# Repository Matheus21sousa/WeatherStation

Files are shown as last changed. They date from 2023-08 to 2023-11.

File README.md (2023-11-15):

# PROJETO -> Estação meteorológica de baixo custo!

> **Strater:** *Matheus M. Sousa*
>
> **Contributors:** *Marcos Paulo L. Resende*; *André Luiz V. Silva*; *Juvenal Caetano de Barcelos*; *Júlio César Neves dos Santos*
>
> O presente repositório, visa documentar a trajetória por trás da elaboração de uma estação meteorológica com base em Arduíno e peças impressas.
>
> A utilização de todo e qualquer arquivo aqui presente deve seguir a metodologia de citação com base nas normas estabelecidas pela ABNT. 

---

**COMPONENTES ELETRÔNICOS:**

Como microcontrolador, pode ser utilizado qualquer dispositivo ***Arduino*** ou ***ESP***.

Abaixo, estão listados todos os componentes eletrônicos adicionais:

| *NOME* | *QUANTIDADE* | *FUNÇÃO* |
| :--- | :---: | :--- |
| **DHTxx** | 01 | Umidade e temperatura do ar |
| **SHT20** | 01 | Umidade e temperatura do solo |
| **Hall 49e** | 02 | Determina o número de basculadas |
| **RTC - DS3231** | 01 | Armazena informações de data e hora |
| **Módulo micro SD - 4MD36** | 01 | Grava informações em cartão micro SD |

---

**INSTRUÇÕES PARA IMPRESSÃO DAS PEÇAS:**

- **Abrigo meteorológico:**
  1. *Peça A:* Base;
  2. *Peça B:* Peças intermediárias (mínimo 4);
  3. *Peça C:* Topo;
  4. *Espaçador:* Peças de 1 cm de altura para limitar a distância de encaixe entre as peças anteriores;
- **Báscula:**
  - Imprimir a peça com altura entre camadas igual ou inferior á 0,2 mm;
  - Reduzir a rugosidade dos compartimentos com o uso de uma lixa d'água;
  - A volumetria dos compartimentos deve ser estimada por meio de testes laboratoriais;  
- **Funil:**
  - Fundir as peças (*Funil externo* + *Funil interno* + *Funil interno - suporte*) c/ cola *super bonder*;
  - Verificar se orifício do funil interno não esteja obstruído após impressão; 

---

**EVENTOS PRESENTES:**

| *ACRÔNIMO* | *EVENTO* | *EDIÇÃO* | *LOCAL* |
| :---: | :---: | :---: | :---: |
| **MNR** | Mostra nacional de robótica | 2023 | Salvador |
| **SIN** | XIII Simpósio de iniciação científica | 2023 | Patos de Minas |
| **SIN** | XII Simpósio de iniciação científica | 2022 | Uberlândia |

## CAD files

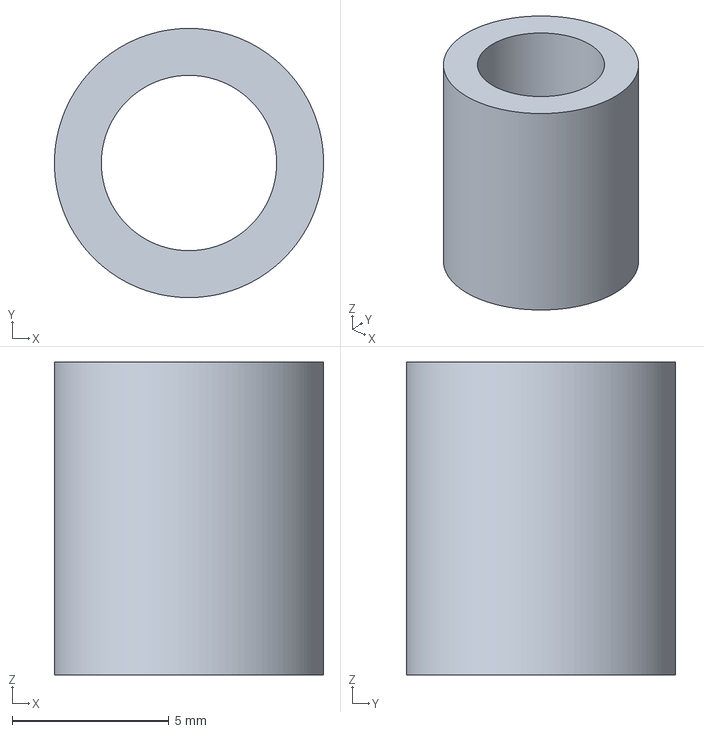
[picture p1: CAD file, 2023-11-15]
3D_Parts/WS - Abrigo met. - Espaçador .3mf
8.60 x 8.60 x 10.0 mm

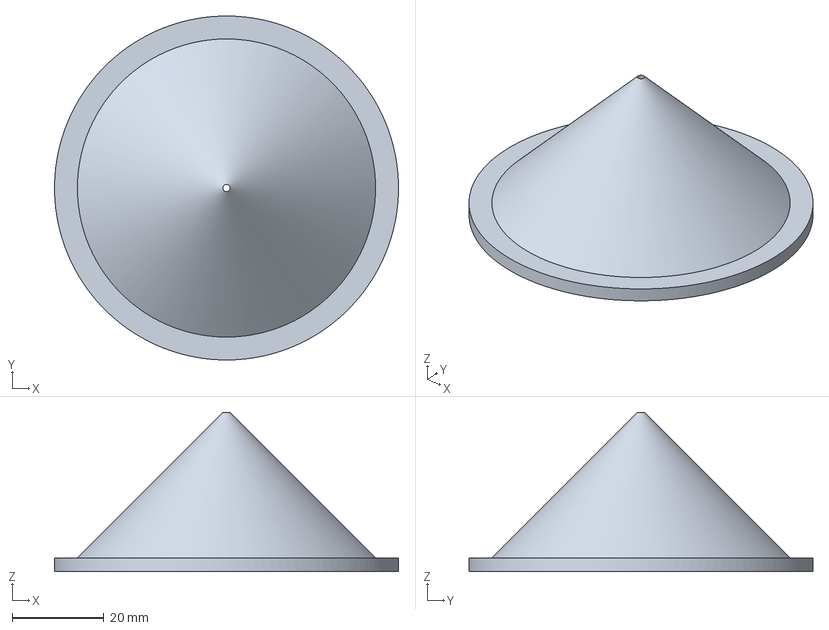
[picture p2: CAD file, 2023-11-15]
3D_Parts/WS - Pluviômetro - Funil interno .3mf
75.0 x 75.0 x 34.7 mm

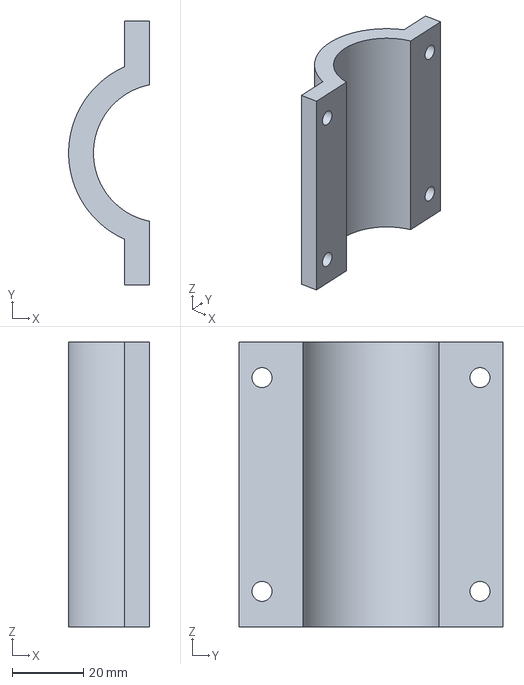
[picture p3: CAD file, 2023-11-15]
3D_Parts/WS - Trava universal suportes .3mf
22.7 x 74.0 x 80.0 mm

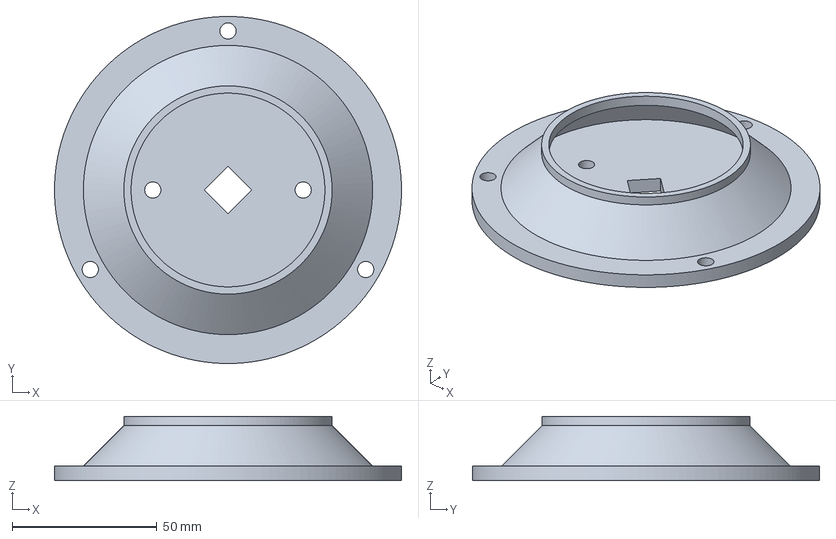
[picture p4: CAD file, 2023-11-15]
3D_Parts/WS - Abrigo met. - Peça A .3mf
120.0 x 120.0 x 22.1 mm

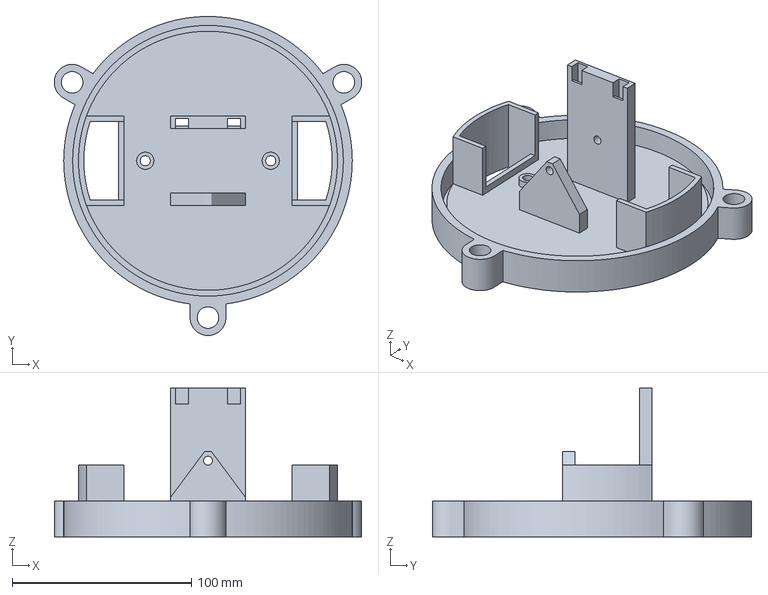
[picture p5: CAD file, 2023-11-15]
3D_Parts/WS - Pluviômetro - Extra I .3mf
171.6 x 178.0 x 83.0 mm

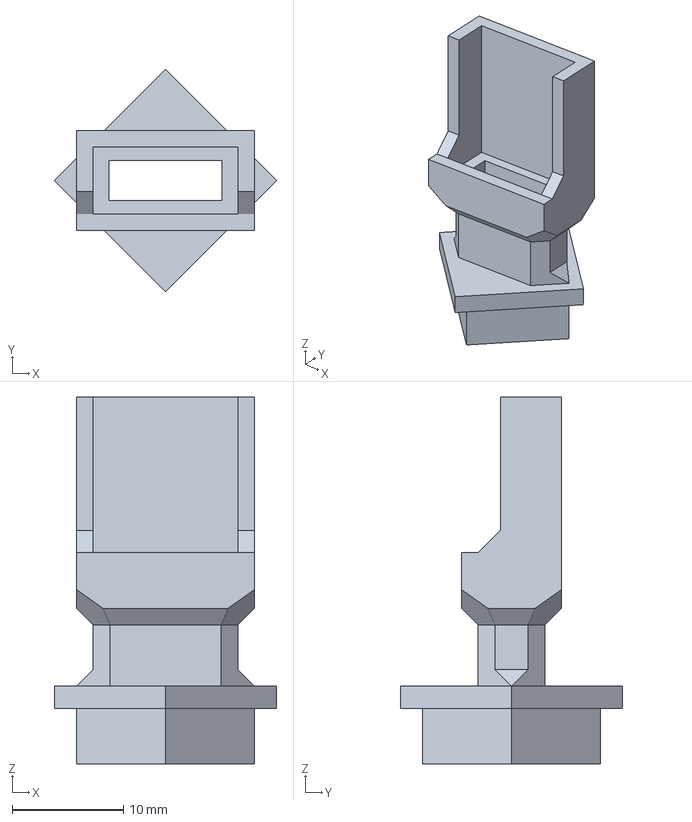
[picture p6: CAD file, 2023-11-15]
3D_Parts/WS - Abrigo met. - Suporte DHT .3mf
20.0 x 20.0 x 33.0 mm

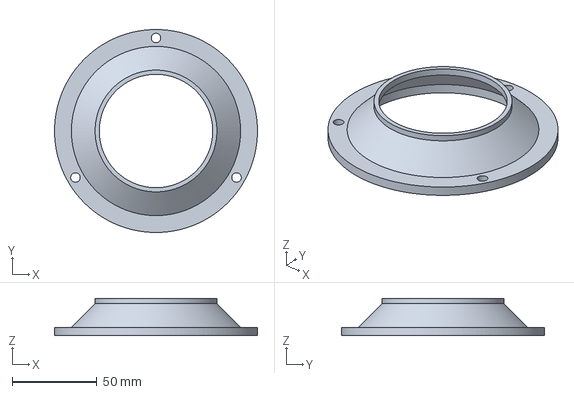
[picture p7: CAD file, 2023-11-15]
3D_Parts/WS - Abrigo met. - Peça B .3mf
120.0 x 120.0 x 22.1 mm

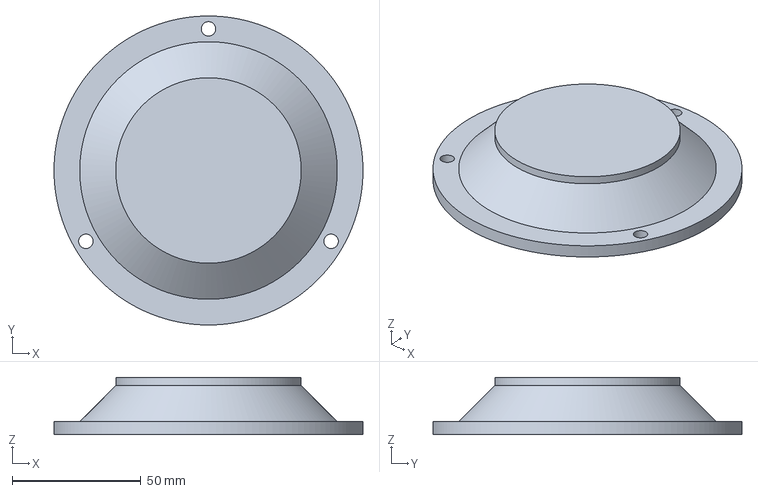
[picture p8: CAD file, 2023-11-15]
3D_Parts/WS - Abrigo met. - Peça C .3mf
120.0 x 120.0 x 22.1 mm

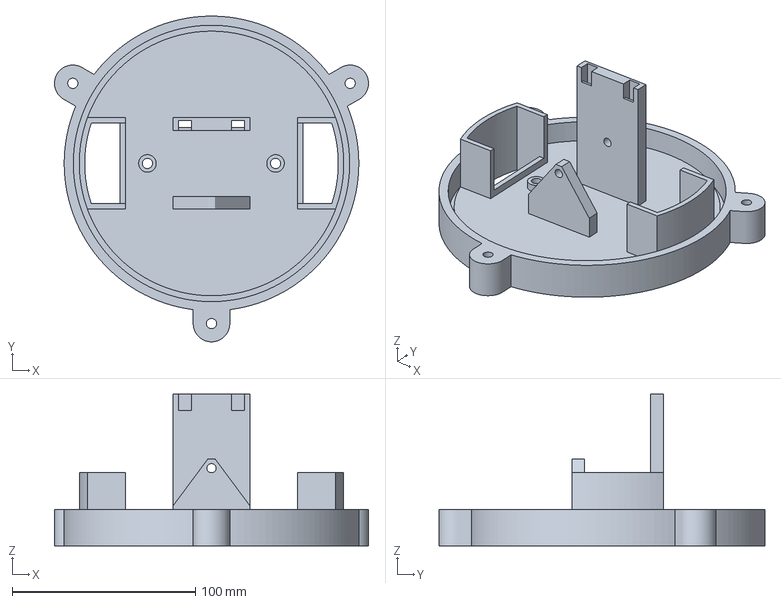
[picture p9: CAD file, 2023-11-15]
3D_Parts/WS - Pluviômetro - Base .3mf
171.6 x 178.0 x 83.0 mm

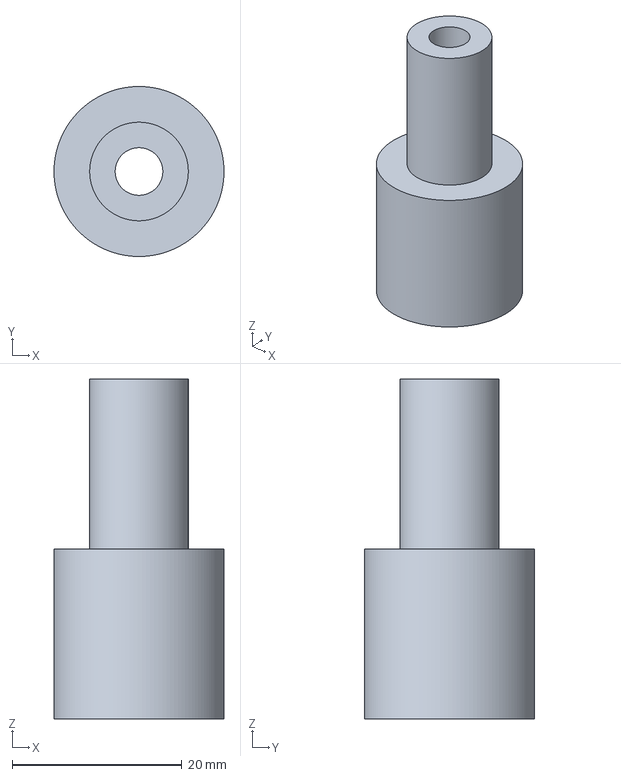
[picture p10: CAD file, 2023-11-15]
3D_Parts/WS - Pluviômetro - Extra II .3mf
20.0 x 20.0 x 40.0 mm

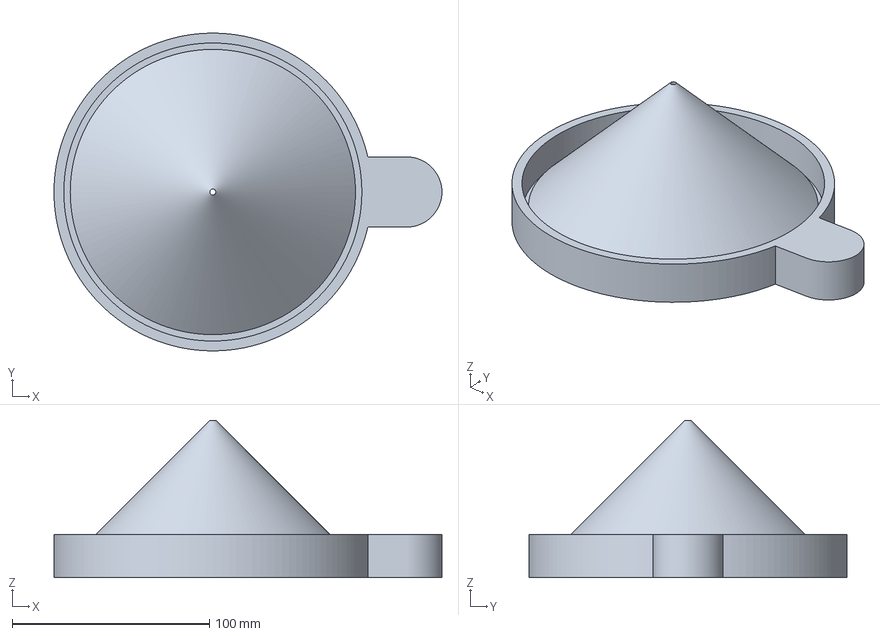
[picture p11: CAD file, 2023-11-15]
3D_Parts/WS - Pluviômetro - Funil externo .3mf
196.6 x 161.0 x 79.8 mm

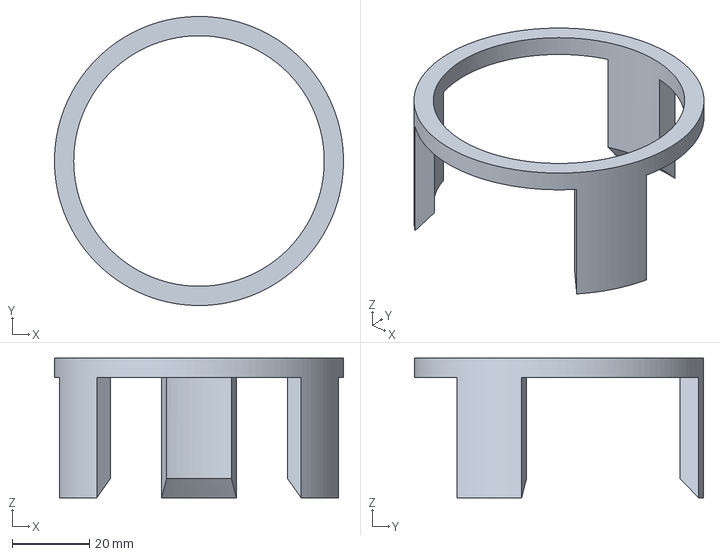
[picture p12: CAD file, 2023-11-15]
3D_Parts/WS - Pluviômetro - Junção funil .3mf
75.0 x 75.0 x 36.2 mm

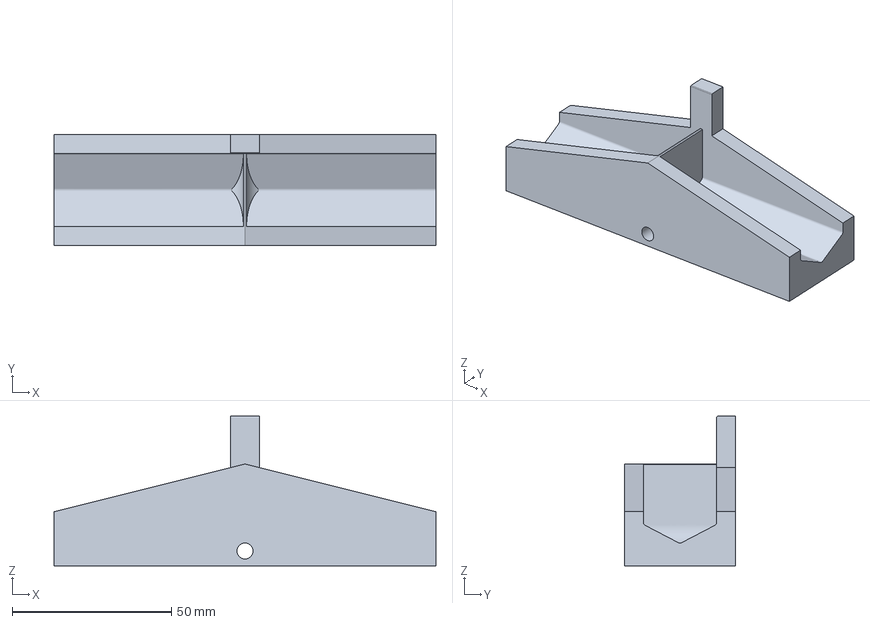
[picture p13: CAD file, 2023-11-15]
3D_Parts/WS - Pluviômetro - Báscula .3mf
120.0 x 35.0 x 47.0 mm

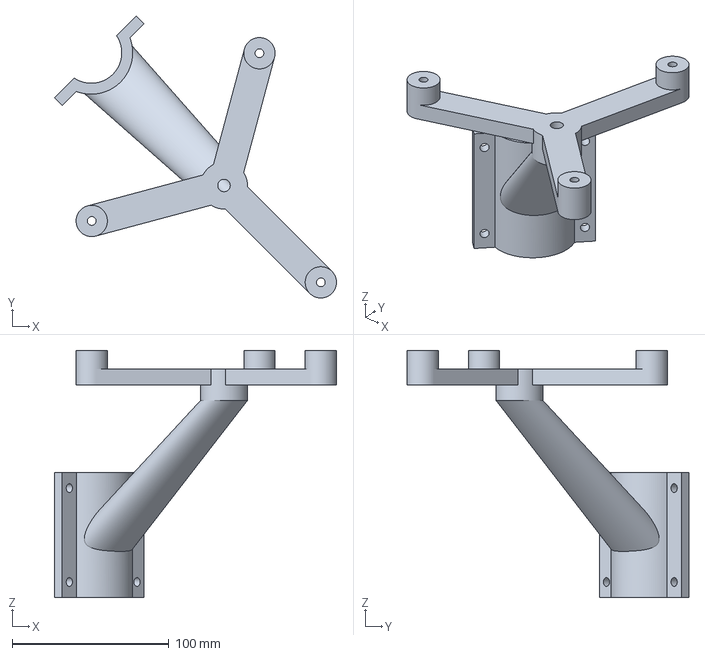
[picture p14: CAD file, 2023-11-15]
3D_Parts/WS - Suporte pluviômetro .3mf
180.2 x 180.2 x 158.0 mm

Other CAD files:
3D_Parts/WS - Suporte abrigo met. .3mf

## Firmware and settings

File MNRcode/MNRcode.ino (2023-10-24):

// MADE BY: Matheus Martins de Sousa //
//
// O presente projeto é aberto a correções
// Use com sabedoria!
// :)
//

// DESCRIÇÃO: Uso de sensores hall para determinar a pluviometria; 

// BIBLIOTECAS UTILIZADAS
#include <Adafruit_Sensor.h>
#include <DHT.h>
#include <DHT_U.h>

// DEFINIÇÃO DE PORTAS
#define DHTPIN 7
#define hallPinD A5 
#define hallPinE A4
// Portas hall (model 49e):
// 5V - Esquerda
// GND - Central
// DATA - Direita

// Selecione a seguir o sensor que está sendo utilizado, retirando as // no início da linha:
#define DHTTYPE    DHT11     // DHT 11
//#define DHTTYPE    DHT22     // DHT 22 (AM2302)
//#define DHTTYPE    DHT21     // DHT 21 (AM2301)

// CONFIGURAÇÃO SENSOR DHT - "TYPE"
DHT_Unified dht(DHTPIN, DHTTYPE);

// VARIÁVEL DE TEMPO
uint32_t delayMS;

// VARIÁVEIS GLOBAIS UTILIZADAS
int oldSignalE = 0;                      
int oldSignalD = 0;
int newSignalE = 0;
int newSignalD = 0;

int deltaE;
int ABSdE;
int deltaD;
int ABSdD;

int b_inst = 0;
int b_acu = 0;
float v = 13.2;
float chuva_inst = 0;
float chuva_acu = 0;
int side = 0; 
float last_refresh = 0;
float time_now = 0;
float delta_time = 0;

// ÍNDICE DE VARIÁVEIS:
// 1. "oldSignalX"      atribuir ao valor da leitura Hall distanciado do ímã
// 2. "newSignalX"      atribuir ao valor lido instantaneamente
// 3. "deltaX"          atribuir a diferença entre a leitura instantânea e a leitur base (newSignalX - oldSignalX) 
// 4. "ABSdX"           módulo do valor obtido em "deltaX"
// 5. "b"               número de basculadas
// 6. "v"               volume de água por basculada, em mL
// 7. "chuva_inst"      valor relativo á multiplicação do número de basculadas (b) * volume por basculada (v), em mL
// 8. "chuva_acu"       somatório de todas as basculadas ao longo do dia, em mm
// 8. "side"            variável que identifica o lado a qual a báscula está pendendo [1 = esquerda / 2 = direita] 
// 9. "last_refresh"    variável que armazena um valor em microsegundos a qual representa a hora da ultima atualização da variável "b"
// 10. "time_now"       variável responsável por armazenar o tempo adquirido por meio da função {milis()}; 
// 11. "delta_time"     variável responsável por receber o valor advindo da operação de subtração entre o "time_now" e "last_refresh"

// FUNÇÕES UTILIZADAS
void bascula();                   // Função que contabiliza basculadas 
void dados();                     // Função que imprime dados do DHT e da báscula 
void latencia();                  // Função que quantifica a diferênça de tempo entre um conjunto de dados e outro
void espera();                    // Função delay 

// COMUTAR EXECUÇÃO DE DIFERENTES FUNÇÕES
unsigned long tempoB=0;
unsigned long tempoD=0;
unsigned long tempoL=0;

bool comutarB = false;
bool comutarD = false;
bool comutarL = false;

// VOID SETUP
void setup() {
  pinMode(hallPinE, INPUT_PULLUP);
  pinMode(hallPinD, INPUT_PULLUP);
  Serial.begin(9600);
  dht.begin();
  sensor_t sensor;
  dht.temperature().getSensor(&sensor);
}

// VOID LOOP
void loop(){
  bascula();
  dados();
  latencia();
  espera();
}

// FUNÇÃO 01 - Contabiliza basculadas
void bascula(){
  if(comutarB){
  
  // CALCULO
  chuva_inst = b_inst*v;
  chuva_acu = 10*b_acu*v/157.49;

  // INICIO:
    if (side == 0){
      newSignalE = analogRead(hallPinE);
      newSignalD = analogRead(hallPinD);
      oldSignalE = newSignalE;
      oldSignalD = newSignalD;
      side++;
    }

    //Sempre deve começar basculada para a esquerda
    else if (side == 1){ 
      newSignalD = analogRead(hallPinD); 
      deltaD = oldSignalD - newSignalD;
      ABSdD = abs(deltaD); 

      if (ABSdD >=30){
        side++;
        b_inst++;
        b_acu++;
        newSignalE = analogRead(hallPinE);
        oldSignalE = newSignalE;
        last_refresh = millis();
      }
    }

    //Bascula para o lado direito
    else if (side == 2){ 
      newSignalE = analogRead(hallPinE); 
      deltaE = oldSignalE - newSignalE;
      ABSdE = abs(deltaE); 

      if (ABSdE >=30){
        side--;
        b_inst++;
        b_acu++;
        newSignalD = analogRead(hallPinD);
        oldSignalD = newSignalD;
        last_refresh = millis();
      }
    }

  // COMUTA FUNÇÃO ACIMA
  tempoB=millis();
  comutarB = false;    
  }
}

// FUNÇÃO 02 - Lê DHT e imprimir dados de umidade, temperatura e chuva 
void dados(){
  if(comutarD){
    sensors_event_t event;
    Serial.print("{\"deviceId\":1,\"data\":");
    
    // ACCUMULATED RAIN
    Serial.print("{\"chuvaAcumulada\":");
    Serial.print(chuva_acu, 2);
    Serial.print(", ");

    // INSTANT RAIN
    Serial.print("\"chuvaInstantanea\":");
    Serial.print(chuva_inst, 2);
    Serial.print(", ");

    //Serial.print("side: ");
    //Serial.print(side);
    //Serial.print(", ");

    // TEMPERATURA
    dht.temperature().getEvent(&event);
    Serial.print("\"temperatura\":");
    Serial.print(event.temperature);
    Serial.print(", ");

    // HUMIDADE
    dht.humidity().getEvent(&event);
    Serial.print("\"umidade\":"); 
    Serial.print(event.relative_humidity);
    Serial.println("}}");

    // TIME
    //Serial.print(delta_time, 5);
    //Serial.print(" - "); 
    //Serial.println(time_now, 5);
    
    // COMUTA FUNÇÃO ACIMA
    tempoD=millis();
    comutarD = false;    
  }
}

// FUNÇÃO 3 - LATENCIA DE DADOS
void latencia(){
  if(comutarL){
    
    time_now = millis();
    delta_time = time_now - last_refresh;
    
    // CALCULA TEMPO ENTRE MEDIDAS: SE SUPERIOR A X, ZERA O NÚMERO DE BASCULADAS "b"
    if(delta_time > 20000){  // 20 segundos sem novos dados zera a leitura instantanea
      b_inst = 0;
      delta_time = 0; 
    }

    // COMUTA FUNÇÃO ACIMA
    tempoL=millis();
    comutarL = false;    
  }
}

// Definições de intervalo (delay) de cada atividade //
void espera(){
  // FUNÇÃO 01 - BASCULA
  if(!comutarB && millis() - tempoB>=200){
    comutarB = true;
  }
  // FUNÇÃO 02 - DHT E DADOS
  if(!comutarD && millis() - tempoD>=5000){
    comutarD = true;
  }
  // FUNÇÃO 03 - LATÊNCIA
  if(!comutarL && millis() - tempoL>=500){
    comutarL = true;
  }
}

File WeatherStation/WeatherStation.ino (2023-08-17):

/* ESTAÇÃO METEOROLÓGICA
    By: Matheus M. Sousa 
    O presente projeto é aberto a correções
    Use com sabedoria!
    :)
*/ 

// BIBLIOTECAS UTILIZADAS
#include <Wire.h>
#include <Adafruit_Sensor.h>
#include <DHT.h>
#include <DHT_U.h>
#include "DFRobot_SHT20.h"
#include "RTClib.h"
#include <SD.h>
#include <SPI.h>

// DEFINIÇÃO DE PORTAS
#define ampolae 2
#define ampolad 4
#define chipSelect 5
#define DHTPIN 7
#define DHTTYPE DHT11
//#define DHTTYPE DHT22 (AM2302)
//#define DHTTYPE DHT21 (AM2301)

// Descrição das portas //
// RTC:
//       SCL = Porta 01 I²C
//       SDA = Porta 02 I²C
// SHT:
//       SCL = Porta A5 I²C (Amarelo)
//       SDA = Porta A4 I²C (Verde)
// Leitor SD:
//       CS = Porta 05
//       SCK = Porta 13
//       MOSI = Porta 11
//       MISO = Porta 12

// Inicializa o RTC //
RTC_DS3231 rtc;

// Inicializa o SHT //
DFRobot_SHT20 sht20(&Wire, SHT20_I2C_ADDR);

// Define [nº de dias da semana] [nº de meses do ano] e nome dos dias da semana //
char daysOfTheWeek[7][12] = {"Domingo", "Segunda", "Terça", "Quarta", "Quinta", "Sexta", "Sábado"};

// Funções utilizadas //
void bascula();            // Função que contabiliza basculadas //
void dados();              // Função que imprime dados do DHT e da báscula //
void espera();             // Função delay //

unsigned long tempoB = 0;
unsigned long tempoD = 0;

// Comutando as funções //
bool comutarB = false;
bool comutarD = false;
// ComutarB = Função da báscula //
// ComutarD = Função de imprimir dados //

// Configuração do sensor DHT - pinagem e tipagem //
DHT_Unified dht(DHTPIN, DHTTYPE);

// Variável de delay //
uint32_t delayMS;

// VARIÁVEIS UTILIZADAS 
int b = 0;        // Nº de basculadas 
float v = 1;      // Volume da basculada - Deve ser calibrado
int side = 0;
// lado = 0 - Início 
// lado = 1 - Esquerda 
// lado = 2 - Direita 

void setup() {
  pinMode(ampolae, INPUT_PULLUP); //Define pino de entrada
  pinMode(ampolad, INPUT_PULLUP); //Define pino de entrada
  Serial.begin(9600);
  dht.begin();
  sensor_t sensor;
  dht.temperature().getSensor(&sensor);

  // RTC - Permite testar se está funcionando //
  if (! rtc.begin()) { 
    Serial.println("RTC não encontrado"); // Imprime, em caso de erro
    while (1); // Fica em loop
  }
  if (rtc.lostPower()) { //Para inicializar o RTC pela primeira vez, utilize um dos dois códigos abaixo: //
    // rtc.adjust(DateTime(F(__DATE__), F(__TIME__))); // Captura do computador as informações de data e hora //
    // rtc.adjust(DateTime(2023, 7, 27, 23, 50, 00)); // Inserir manualmente [ano, mês, dia, hora, minutos, segundos] //
  }

  // SHT - Inicia o sensor
  sht20.initSHT20();
  sht20.checkSHT20();

  // Leitor SD - Permite testar se está funcionando //
  if (!SD.begin(chipSelect)){
    Serial.print("Error to acess the card!");
    Serial.print("Verify your card/conections and reset");
    return;
  }
}

// Execução de atividades simultâneas //
void loop() {
  bascula();
  dados();
  espera();
}

// Atividade 01 - Contabilização de basculadas //
void bascula() {
  if (comutarB) {
    // Início // Para lado == 0 //
    if (!digitalRead(ampolad) && side == 0) {
      b++;
      side++;
      side++;
    }
    else if (!digitalRead(ampolae) && side == 0) {
      b++;
      side++;
    }
    // Execução // Para lado != 0 //
    else if (!digitalRead(ampolad) && side == 1) {
      b++;
      side++;
    }
    else if (!digitalRead(ampolae) && side == 2) {
      b++;
      side--;
    }
    // Comuta a atividade 01 //
    tempoB = millis();
    comutarB = false;
  }
}

// Atividade 02 - Lê DHT e imprime: Data, Hora, Umidade, Pluviosidade //
void dados() {
  if (comutarD) {

    // Chama a função do RTC //
    DateTime now = rtc.now(); // Chama função do RTC
    Serial.print("Data: "); 
    Serial.print(now.day(), DEC); 
    Serial.print('/'); 
    Serial.print(now.month(), DEC); 
    Serial.print('/'); 
    Serial.print(now.year(), DEC); 
    Serial.print(',');    
    Serial.print(" Hora: "); 
    Serial.print(now.hour(), DEC); 
    Serial.print(':'); 
    Serial.print(now.minute(), DEC);
    Serial.print(':'); 
    Serial.print(now.second(), DEC); 
    Serial.print(','); 

    // Chama a função do DHT //
    sensors_event_t event;
    dht.temperature().getEvent(&event); // Lê temperatura do ar
    if (isnan(event.temperature)) {
      Serial.print(F("Erro ao ler a temperatura!"));
    }
    else {
      Serial.print(F(" Temp. do Ar: "));
      Serial.print(event.temperature);
      Serial.print(F("°C"));
      Serial.print(','); 
    }
    dht.humidity().getEvent(&event); // Lê umidade do ar
    if (isnan(event.relative_humidity)) {
      Serial.print(F("Erro ao ler a umidade!"));
    }
    else {
      Serial.print(F(" Umidade do Ar: "));
      Serial.print(event.relative_humidity);
      Serial.print(F("%"));
      Serial.print(','); 
    }

    // Chama o SHT 
    float soilHum = sht20.readHumidity();
    float soilTem = sht20.readTemperature();
    Serial.print(F(" Temp. do solo: ")); Serial.print(soilTem); Serial.print(F("°C,"));
    Serial.print(F(" Umidade do solo: ")); Serial.print(soilHum); Serial.print(F("%,"));

    // Imprime variável chuva //
    float chuva = b * v;
    Serial.print(F(" Chuva atual: ")); Serial.print(chuva); Serial.print(F(" mm"));
    Serial.print(','); 
    Serial.println();

    // Gravação de dados no SD //
    File dataFile = SD.open("datalog.txt", FILE_WRITE);
    if (dataFile){
      // Grava: Data e horário//
      dataFile.print("Data: "); 
      dataFile.print(now.day(), DEC); 
      dataFile.print('/'); 
      dataFile.print(now.month(), DEC); 
      dataFile.print('/'); 
      dataFile.print(now.year(), DEC); 
      dataFile.print(',');    
      dataFile.print(" Hora: "); 
      dataFile.print(now.hour(), DEC); 
      dataFile.print(':'); 
      dataFile.print(now.minute(), DEC);
      dataFile.print(':'); 
      dataFile.print(now.second(), DEC); 
      dataFile.print(',');

      // Grava: Temperatura do Ar //
      dht.temperature().getEvent(&event);
      if (isnan(event.temperature)) {
        dataFile.print(F("Erro ao ler a temperatura!"));
      }
      else {
        dataFile.print(F(" Temp. do ar: ")); dataFile.print(event.temperature); dataFile.print(F("°C,"));
      }

      // Grava: Umidade do Ar //
      dht.humidity().getEvent(&event);
      if (isnan(event.relative_humidity)) {
        dataFile.print(F("Erro ao ler a umidade!"));
      }
      else {
        dataFile.print(F(" Umidade do ar: ")); dataFile.print(event.relative_humidity); dataFile.print(F("%,"));
      }

      // Grava: Temperatura do Solo //
      dataFile.print(F(" Temp. do solo: ")); dataFile.print(soilTem); dataFile.print(F("°C,"));

      // Grava: Umidade do Solo //
      dataFile.print(F(" Umidade do solo: ")); dataFile.print(soilHum); dataFile.print(F("%,"));

      // Grava: Pluviometria //
      dataFile.print(F(" Chuva atual: ")); dataFile.print(chuva); dataFile.print(F(" mm,"));
      dataFile.println();
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

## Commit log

2023-07-13 Iniciando a prototipagem
    Código do primeiro protótipo utilizando red-switch para validar uma basculada e um DHT 11 para estimar umidade e temperatura do ar.
2023-07-13 Alterações de escrita e RTC
    Modificações nos comentários.
2023-07-13 Peças do pluviômetro
    Modelos 3D das peças impressas.
    [Bascula_2.0.stl, Funil_2.0.stl]
2023-07-28 V2.0 - DHT + SHT + Grava com horário
    Nessa versão, retrabalhada, as seguintes funções estão funcionando:
    - Temp. e umidade do ar (DHT-11);
    - Temp. e umidade do solo (SHT-20);
    - Pluviosidade com ReedSwitch;
    - Grava no SD com horário (RTC);
    Foi melhorado a escrita de algumas funções e pretende-se trocar o reedSwitch do pluviômetro para sensores Hall.
2023-08-10 Atualização de modelos - v2.2
    Base: Aumento do diâmetro do furo de conexão com báscula para 5 mm; Elevação do centro de rotação; Aumento no sulco de encaixe para tubo; incremento na espessura da parede de suporte do tubo;
    Báscula: Aumento da furação de conexão com a báscula; Aumento na profundidade da base para suportar a furação maior;
    Abrigo met:
    A. Peça inicial;
    B. Peças intermediárias;
    C. Peça superior;
    [Bascula_2.0.stl, Funil_2.0.stl, WS - Abrigo met. - Peça A.stl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]
2023-08-17 Add BasculaHall V 1.0
    Adição do código da báscula com o uso de dois sensores hall (***model 49e***).
2023-09-26 Atualização de peças V2.0
    MODIFICAÇÕES::
    - Abrigo met. (Peça A): aumento do espaço para o suporte do DHT;
    - Abrigo met. (Suporte DHT): adição de peça que irá encaixar na base do abrigo e irá suportar o DHT;
    - Base báscula: Modificação no formato da base da báscula para preencher toda a área do tubo, escoar a água coletada e adição de orifícios para colocar barras roscadas que servem para calibrar o ângu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
    - Báscula: modificação no orifício do ímã para comportar ímã mais forte;
    - Funil: adição de funil externo e interno com a intenção de reduzir a turbulência do fluxo de água e melhorias na resistência da parede.
    [WS - Abrigo met. - Espaçador .stl, WS - Abrigo met. - Peça A.stl, WS - Abrigo met. - Peça B.stl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]
2023-09-27 Modificações no funil interno e na base da báscula
    ### MODIFICAÇÕES NO FUNIL:
    O uso de pés aderidos ao funil interno dificulta a impressão e gera uma peça de baixa qualidade. Portanto, o funil interno foi separado em duas peças:
    1. ***Funil interno***: Sendo o funil em si;
    2. ***Funil interno (suporte)***: Sendo uma peça intermediária entre o funil interno e o funil externo;
    ### MODIFICAÇÕES NA BASE BÁSCULA:
    Foram realizadas modificações na base da báscula, para deixá-la com as bordas do encaixe para pés arredondadas e adição das peças "***Base básculas (pés)***" que servirão para nivelar o pluviômetro.
    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
    [WS - Base báscula - Pés.stl, WS - Base báscula 3.2.stl, WS - Base báscula.stl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]
2023-10-24 Adições: Código de sensores e código usado na MNR
    Adições dos códigos de cada sensor utilizado juntamente aos datasheet dos mesmos.
    Ainda, foi adicionado o código utilizado durante a Mostra Nacional de Robótica 2023 - Salvador, ao qual, foram utilizados a báscula e o DHT acoplado ao projeto UAI.py.
2023-11-15 Add: Suporte pluviometro e abrigo met.
    A presente versão adiciona as peças que irão dar suporte ao abrigo meteorológico e pluviômetro, permitindo acoplá-los em um tubo de diâmtro nominal de 35 mm, c/ espessura externa de até 39 mm.
    [WS - Pluviometro - Base.3mf, WS - Suporte abrigo met..3mf, WS - Suporte pluviometro.3mf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]
2023-11-15 Add: Novas peças // Formato 3mf // Nomeclatura
    I. Todas as peças passaram por uma padronização para a furação que recebe parafusos, saindo de 6,2 mm para 5,6 mm;
    II. Ainda, todos os modelos foram atualizados, passando do formato .stl para .3mf;
    III. A nomeclatura mudou. Agora as peças vão ser divididas quanto ao sensor que integram. Ex.: A báscula pertence ao pluviômetro, portanto temos "Pluviômetro - Báscula";
    IV. As peças base báscula e pés passam á serem peças extras do pluviômetro, visto que não serão utilizadas na prática, apenas para demonstrações. Logo:
    a. "WS - Pluviômetro - Extra I" = "Base" para ser utilizada em bancada;
    b. "WS - Pluviômetro - Extra II"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
    [WS - Abrigo met. - Espaçador .3mf, WS - Abrigo met. - Espaçador .stl, WS - Abrigo met. - Peça A.stl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]
